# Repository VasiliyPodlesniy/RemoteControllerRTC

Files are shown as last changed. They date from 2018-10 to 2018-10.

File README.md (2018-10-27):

# RemoteControllerRTC
Печатная плата пульта дистанционного управления таймерной подсистемой испытательного полигона соревнований Кубок РТК.
Разработанный протокол прикладывается.

Проект выполнен в рамках рабочей деятельности в ЦНИИ РТК.

Функционал изделия:
- аналоговое измерение напряжения батареи;
- графическое отображение данных на OLED дисплей по интерфейсу I2C;
- дистанционное управление по радиоканалу;
- обработка сигналов с помощью микроконтроллера ATMega328P-AU;
- генерация звука на динамик.

demo image

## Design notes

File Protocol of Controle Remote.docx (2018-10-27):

# Общая архитектура связи

## Level 0

Данные | 0 | COBS-кодированные данные Level-1 | 0
Длина | 1 | Изменяющаяся | 1

Пакеты начинаются и заканчиваются кодом «0». Контент пакета кодируется по COBS-алгоритму (у кодированных данных не может встретиться код «0» в теле пакета).

## Level 1

Данные | Адрес источника | Тип контента Level-2 | Контент Level-2 | CRC
Длина | 1 | 1 | Изменяющаяся | 1

Контрольная сумма вычисляется как CRC8 всех 1-байтовых слов, входящих в пакет (тип контента, контент, адрес источника, счётчик пакетов). Если длина пакета не кратна 4, то для вычисления контрольной суммы данные пакета дополняются нулями до длины кратной 4-м (нулевые байты «добавляются» в конец пакета).

Адрес источника присвоен устройству – пульту (Slave). Определяется значением комбинации битов (0 - 127).

Тип пакета определяет, как будет производиться парсинг контента.

Тип контента | Протокол Level-2
“P” (0x50) | Адресный протокол точка-точка (Point-to-Point protocol – PtP)
“A” (0x41) | Протокол уведомления (ACK protocol – AP)

## Level 2

### ACK protocol (AP)

Данный протокол используется для проверки наличия связи между устройствами. В пакете передаются следующие данные: адрес устройства-отправителя, значение напряжения на устройстве.

Данные | Адрес приёмника | Уровень напряжения
Длина | 1 | 1

Уровень напряжения считывается с регистра АЦП ADCL (ADLAR = 0).

### Point-to-Point protocol (PtP)

Данные | Адрес приёмника | Счетчик пакетов | # старт | # пауза | # сброс | Reserved
Длина | 1 | 1 | 1 | 1 | 1 | 1

В поле «адрес приемника» содержится адрес сервера (Master).

В поле счетчика пакетов содержится информация о номере переданного пакета-дубликата (в случае отсутствия подтверждения от сервера).

В поле «старт» содержится значение (0 или 1), которое является флагом запуска работы таймера.

В поле «пауза» содержится значение (0 или 1), которое является флагом приостановки работы таймера для устройства в отдельности.

В поле «сброс» содержится значение (0 или 1), которое является флагом остановки работы таймера.

Поле Reserved размером в 1 байт содержит зарезервированное место для будущих нужд. По умолчанию заполняется нулями (0b00000000).

Пакет ответа от сервера имеет следующий формат:

Данные | Адрес приемника | “R” (0x44) | # запроса
Длина | 1 | 1 | 2

В адресе приемника указывается адрес пульта-получателя пакета ответа.

В поле запроса помещается информация о номере PtP-пакета, на который отправляется подтверждение.

# Принципы связи

## Поддержка канала

Каждое устройство сети с частотой 2 Гц посылает серверу AP-пакеты для поддержки связи по каналу и мониторинга своей активности с предоставлением информации об уровне заряда своей батареи. Это необходимо для детектирования наличия подключения, поскольку интерфейс RS-232/422/485 не имеет каких-либо средств для проверки физической связи (phys link).

Привязка порта ввода/вывода к устройству сохраняется не более 1 секунды. Если на порт ввода/вывода сервера не поступали AP-пакеты 1 секунды и более, порт «отвязывается» от устройства, а канал приёма считается отказавшим. Выдается сообщение об ошибке.

На пакеты поддержки связи сервер не отвечает.

## Передача данных

При осуществлении совместного нажатия кнопки старт/стоп с кнопкой подтверждения устройство посылает серверу PtP-пакет с командой на выполнения запуска/паузы/остановки работы таймера. В ответ от сервера должен прийти пакет подтверждения, в случае получения пакета подтверждения передача клиентом PtP-пакета считается завершенной, иначе происходит повторная передача.

Запуск таймера осуществляется при совместном нажатии кнопки «старт» и кнопки подтверждения.

Пауза в работе таймера осуществляется при повторном совместном нажатии кнопки «старт» и кнопки подтверждения. При получении команды «пауза» сервер выделяет для устройства отдельное независимое окно с собственным таймером. Для закрытия дополнительно выделенного окна необходимо осуществить повторное совместном нажатие кнопки «старт» и кнопки подтверждения.

Остановка работы таймера и осуществляется при совместном однократном нажатии кнопки «стоп» и кнопки подтверждения. Для обновления и сброса таймера необходимо повторно нажать кнопку «стоп» и кнопку подтверждения.

# Структура сети

Сеть коммуникации устройств строится по структуре «звезда».

Каждый Slave имеет в качестве своих параметров значения Mode, Baudrate, Communication Channel, Address. Перечисленные параметры должны совпадать у каждого участника сети.

Slave

Master

Slave

Slave

Slave

Slave

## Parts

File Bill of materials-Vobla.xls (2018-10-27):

Comment | Description | Designator | Footprint | LibRef | Quantity
10мк | Конденсатор полярный | C1, C11 | C1206 | Capacitor_pol | 2
2,2мк | Конденсатор | C2 | C0603 | Capacitor | 1
0,1мк | Конденсатор | C3, C4, C5, C6, C7, C8, C12, C13, C14, C15, C16, C17, C18, C19 | C0603 | Capacitor | 14
16 | Конденсатор | C9, C10 | C0603 | Capacitor | 2
AD8051ARZ | ОУ | DA1 | SO8_H | AD8051ARZ | 1
ATmega328P-AU | Микроконтроллер 64-pin | DD1 | TQFP-32 | ATmega328P-AU | 1
Вход питания |  | GB1 | KLS5-818-С | Battery compartment | 1
18мГн | Катушка индуктивности | L1 | L0603_H | Inductor | 1
1к | Резистор | R1, R3, R4 | R0603 | Resistor_0,125Вт | 3
0 | Резистор | R2, R5 | R0603 | Resistor_0,125Вт | 2
10к | Резистор | R6, R7, R8, R13, R15, R16, R17, R18, R22, R24, R27 | R0603 | Resistor_0,125Вт | 11
47 | Резистор | R9, R10, R11, R12, R14, R19, R20, R21, R23, R25, R28 | R0603 | Resistor_0,125Вт | 11
75 | Резистор | R26 | R0603 | Resistor_0,125Вт | 1
RESET | Кнопка | S1 | DTSM 32 | Button_SMD | 1
DS1040-01 | DIP переключатель | SW1 | DIP1 | DS1040-01 | 1
SS14 | Диод Шоттки | VD1, VD3, VD4, VD5 | SMA | DiodeSchottky | 4
BZX84-C4V7.215 | Стабилитрон | VD2 | SOT23-2_H | DiodeZener | 1
BAV199 | Диодная сборка | VD6 | SOT23-3 | BAV199 | 1
TPD4E001 | Диодная сборка | VD7 | SOT23-6 | TPD4E001 | 1
КТ3130Б9 |  | VT1 | SOT23-3 | КТ3130Б9 | 1
Модуль DIY SSD1306 | Разъем - 4 конт. розетка | X1 | 4HOLE_WIRE | Header_4_sct | 1
Программатор | Разъем - 5 конт. розетка | X2 | 6HOLE_WIRE | Header_6_sct | 1
Разъем для кнопки №1 | Разъем - 2 конт. розетка | X3 | 2HOLE_Button | Header_2_sct | 1
Модуль HC-11 | Разъем - 4 конт. розетка | X4 | 5HOLE_WIRE | Header_5_sct | 1
Разъем для кнопки №2 | Разъем - 2 конт. розетка | X5 | 2HOLE_Button | Header_2_sct | 1
Перемычка | Разъем - 2 конт. вилка | X6 | PLS2-2 | Header_2_plg | 1
Сигнальный светодиод | Разъем - 2 конт. розетка | X7 | 2HOLE_Led | Header_2_sct | 1
Разъем для кнопки №3 | Разъем - 2 конт. розетка | X8 | 2HOLE_Button | Header_2_sct | 1
Разъем для кнопки №4 | Разъем - 2 конт. розетка | X9 | 2HOLE_Button | Header_2_sct | 1
PKLCS1212E4001 | Пьезоизлучатель звуковой | Z1 | Piezoelectric Sounder | Buzzer | 1
8МГц | Кварцевый резонатор | Z2 | QSMD3.2x5 | Crystal | 1

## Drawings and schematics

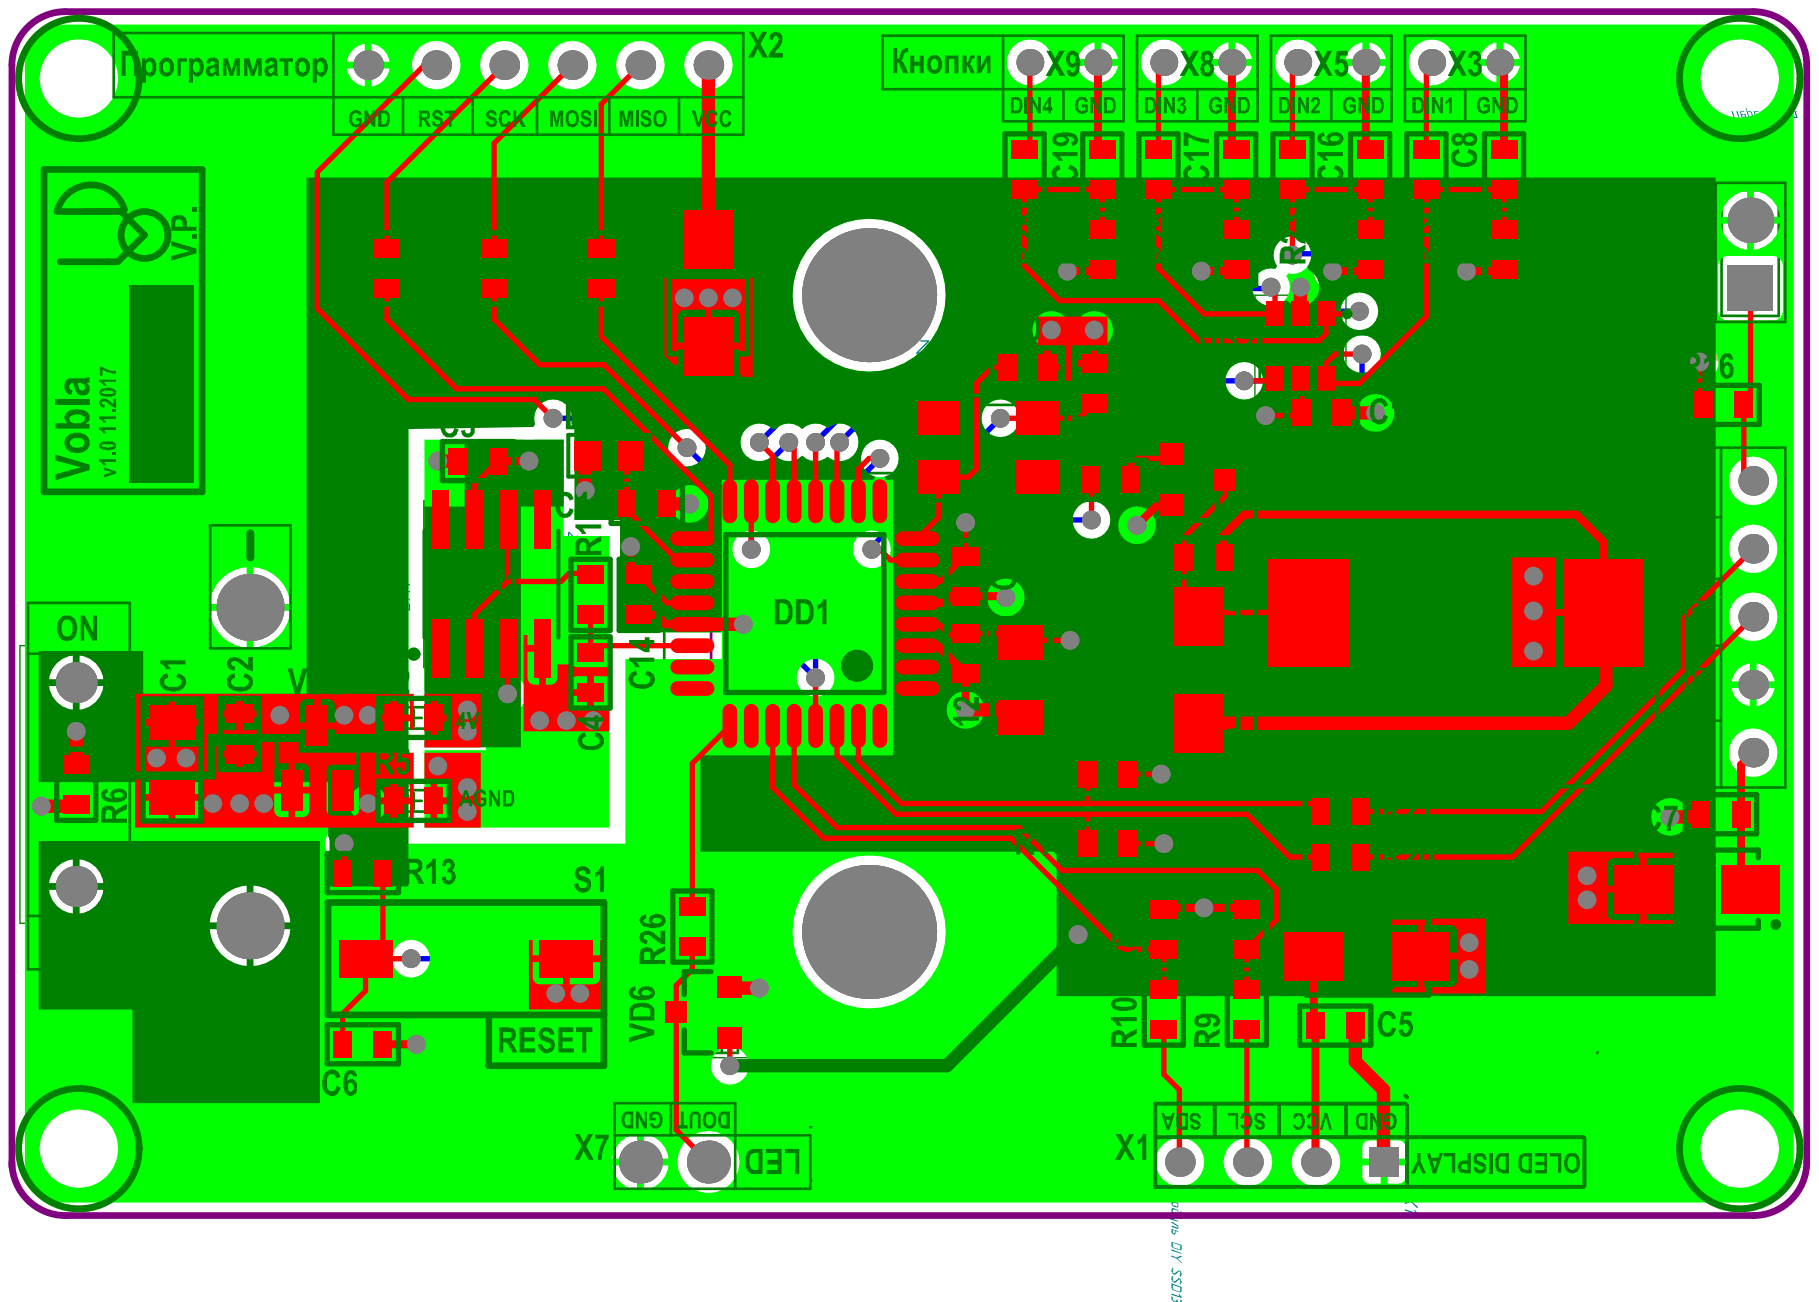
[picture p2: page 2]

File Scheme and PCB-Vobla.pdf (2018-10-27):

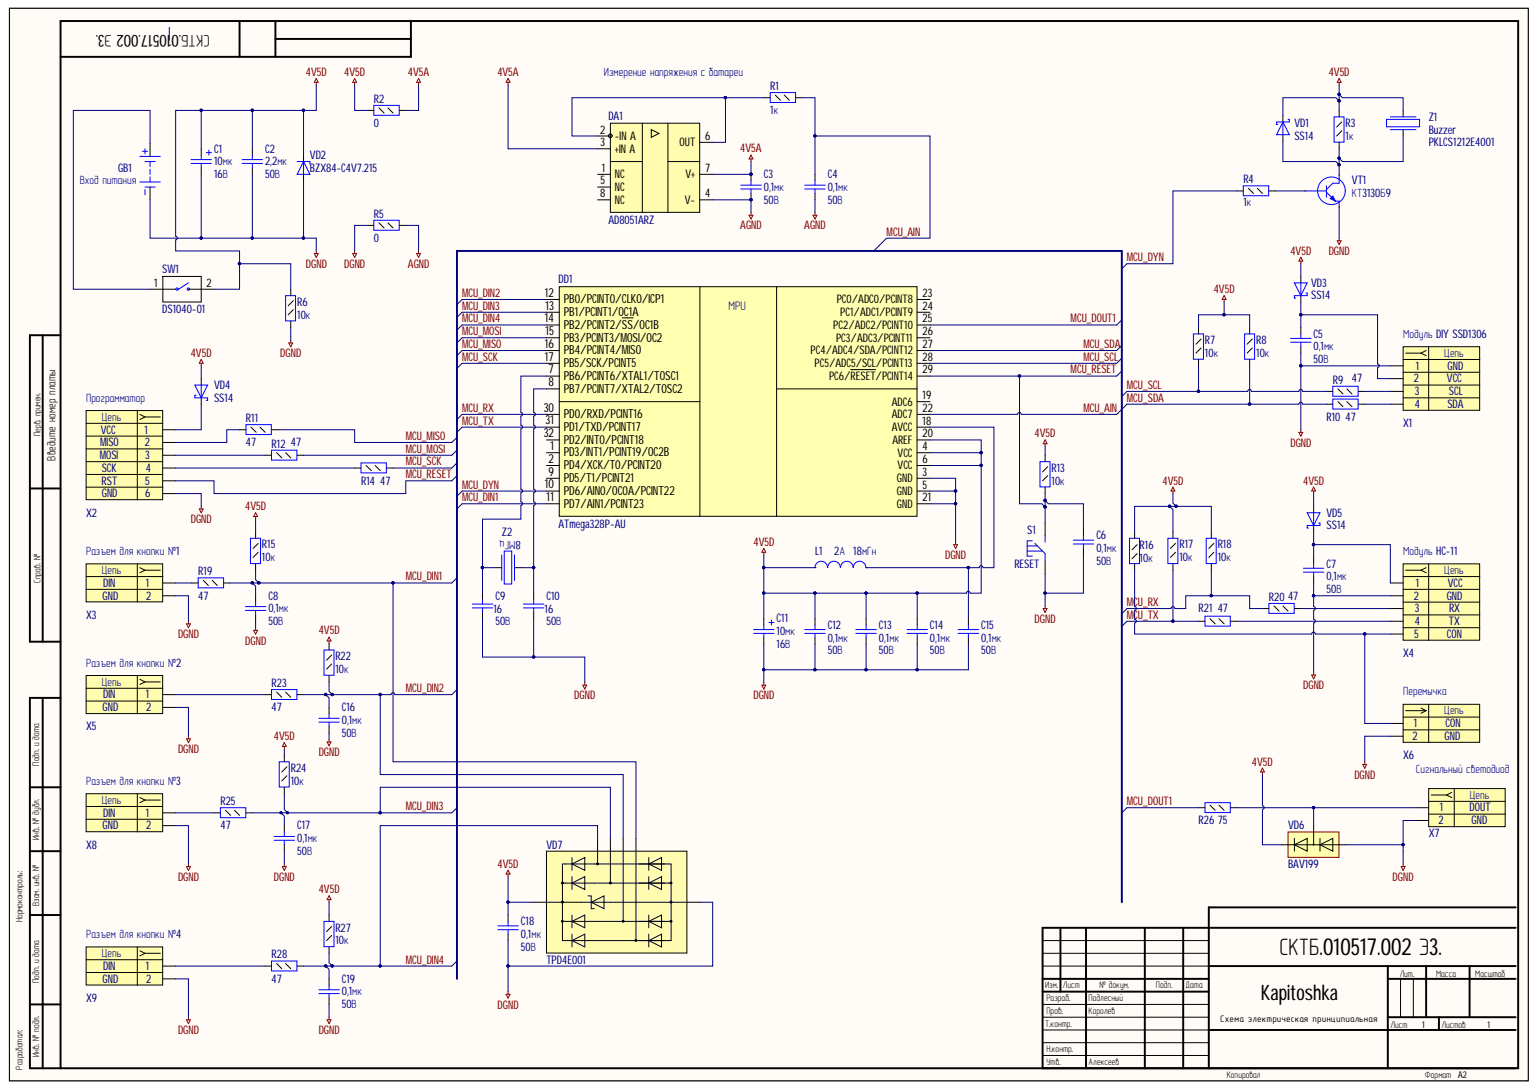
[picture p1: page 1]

DA1
-IN A 2
+IN A 3 | OUT | 6 | 4V5A

Инв. № подл. Инв. № дубл. Подп. и дата Взам. инв. № Подп. и дата Перв. примен. Справ. №

Цепь
DIN | 1

1 | CON
2 | GND

GND | 2

1 | DOUT

СКТБ.010517.002 Э3.

Цепь | | DGND

Kapitoshka Схема электрическая принципиальная | Лит. | Масса | Масштаб

Изм. | Лист | № докум. | Подп. | Дата
Разраб. | | Подлесный
Пров. | | Королев

Н.контр.
Утв. | Алексеев
